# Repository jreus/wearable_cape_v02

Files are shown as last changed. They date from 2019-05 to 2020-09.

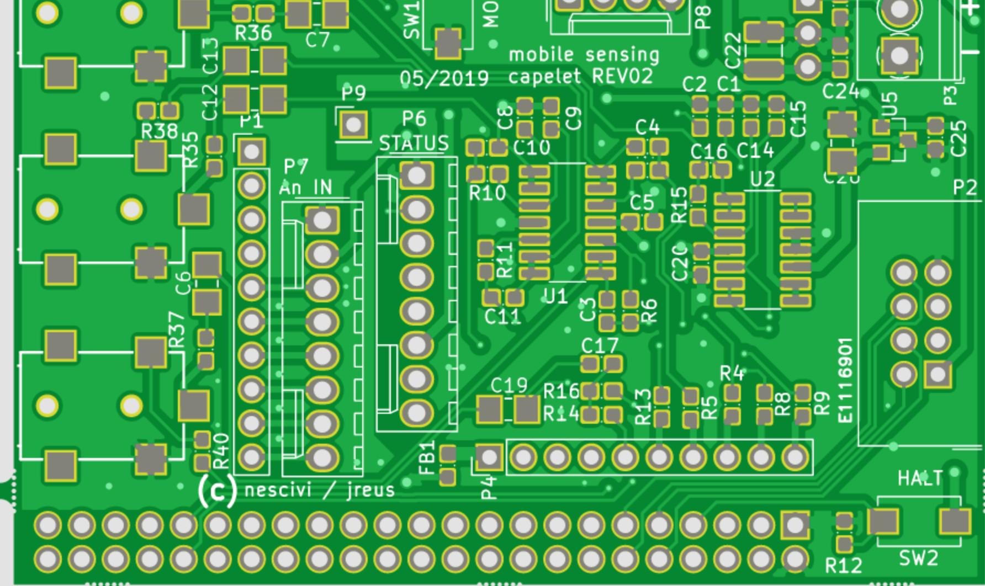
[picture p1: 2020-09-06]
images/REV2.1_wiring_mistake/Screen Shot 2019-05-27 at 19.32.11.png

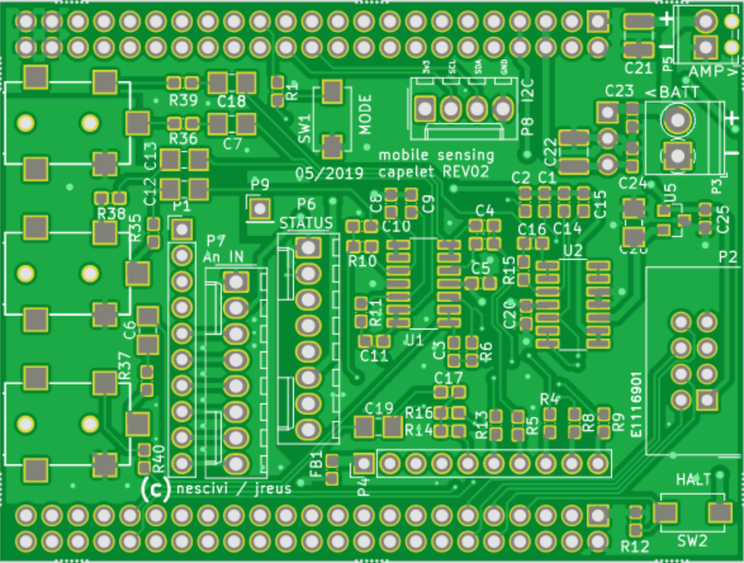
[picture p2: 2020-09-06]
images/REV2.1_wiring_mistake/CUTS-TOP.png

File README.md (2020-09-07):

# wearable_cape_v02

Second version of a wearable sensing/actuating cape for the Augmented Attention Lab (June 2019)

## Changes from v01
- fixed wiring errors from filter circuits to minijack outputs
- removed unused resistors from filter design (two in final stage, one in input stage)
- swapped out resistor-based voltage divider for a dedicated 1.8V reference (MAX6100)
- breakout header for analog inputs
- widen power rail traces from battery to 11.1V source to amplifiers

# 23 MAY 2019 ~ WARNING! First Boards Ordered from Eurocircuits have wiring mistakes!
There was a serious wiring error in these boards, where the 10-pin row of headers that
connect downward into the Bela's analog inputs row and analog outputs row are reversed!
These headers do not correctly match up to the pins on the Bela and thus need to be
sliced and re-routed on the capelet board.

The pin ordering is flipped. So for example, on the Bela, the ground header for analog inputs is
on the bottom. But on the capelet it's at the top.

Likewise, on the Bela the analog outputs ground is on the right, on the capelet it's on the
left.

Possible Solutions (other than making new boards!):

1. Make a pin header/wire adapter that reverses the connections
2. Cut n rewire the capelet

See images/REV2.1_wiring_mistake for more info on the wiring issue...

## More errors
The mode select and halt switches are misnamed on the board, and potentially miswired to the breakout board header.

The actual wiring of the status header on the v2 board is...

1 ~ GND
2 ~ STATUS_LED
3 ~ D11
4 ~ SW_HALT
5 ~ D8
6 ~ MODE_SEL1 / 3v3
7 ~ D9
8 ~ MODE_SEL2

## ToDos (future work)
- Add bypass capacitors to the active filters
- silkscreen labels for switch functionality and outputs
- breakout capability of mode switch, reset switch, & status LEDs
  - user leds, see: http://beaglebone.cameon.net/home/using-the-user-leds
- add additional 2-channel output for full access to all output channels

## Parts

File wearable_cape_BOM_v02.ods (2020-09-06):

Reference | Quantity | Value | Footprint | Supplier | Part No | Cost | Total Cost | in stock | needed | part page
C2 C1 C9 C8 C14 C15 | 6 | 220pF | C0603 | Farnell | 430948 | 0.0645 |  |  |  | https://nl.farnell.com/yageo/cc0603jrnpo9bn221/cap-220pf-50v-5-c0g-np0-0603/dp/430948
C21 C22 | 2 | 10uF | jcr-device:C_1210
C4 C3 C11 C10 C16 C17 | 6 | 440pF (part is 470pF) | C0603 | Farnell | 2496906 | 0.06 |  |  |  | https://nl.farnell.com/walsin/0603n471j500ct/cap-470pf-50v-5-c0g-np0-0603/dp/2496906
C5 C20 C23 C24 C25 | 5 | 100nF | jcr-device:C_0603_SMD_HandSolder | Farnell | 2320793 | 0.0421 |  |  |  | https://nl.farnell.com/multicomp/mc0603b104j250ct/cap-0-1-f-25v-5-x7r-0603/dp/2320793
C7 C6 C13 C12 C18 C19 C26 | 7 | 1uF | jcr-device:C_1206
FB1 | 1 | FILTER | 0603 Ferrite Bead | Farnell | 1781090 | 0.046 |  |  |  | https://nl.farnell.com/murata/blm18kg221sn1d/ferrite-bead-0603-220r-2-2a/dp/1781090
J1 J2 J3 | 3 | Minijack Socket | Lumberg:Lumberg_1503_03 | Farnell | 1216980 | 2.87 |  |  |  | https://nl.farnell.com/lumberg/1503-03/connector-receptacle-3-5mm-phono/dp/1216980
P1 | 1 | BELA_AINS | jcr-conn:PinHeader_1x10_P2.54mm_Vertical
P2 | 1 | SERIAL_BREAKOUT | jcr-conn:IDC-Header_2x04_P2.54mm_Vertical
P3 | 1 | CONN_01X02_BATTERY | jcr-conn:TerminalBlock_Phoenix_PT_H_1x02_P3.50mm
P4 | 1 | BELA_AOUTS | jcr-conn:PinHeader_1x10_P2.54mm_Vertical
P5 | 1 | PWR_OUT_AMPS | jcr-conn:TerminalBlock_Phoenix_MPT_1x02_P2.54mm
P6 P7 | 2 | 8-pin Molex | jcr-conn:Molex_KK-254_1x08_P2.54mm_Vertical
P8 | 1 | 4-pin Molex | jcr-conn:Molex_KK-254_1x04_P2.54mm_Vertical
P9 | 1 | CONN_1 | jcr-conn:PinHeader_1x01_P2.54mm_Vertical
R1 | 1 | 100 | R0603 | Farnell | 2447227 | 0.006 |  |  |  | https://nl.farnell.com/multicomp/mcwr06x1000ftl/res-100r-1-0-1w-0603-thick-film/dp/2447227
R12 | 1 | 10k | R0603 | Farnell | 2447230 | 0.006 |  |  |  | https://nl.farnell.com/multicomp/mcwr06x1002ftl/res-10k-1-0-1w-0603-thick-film/dp/2447230
R37 R36 R35 R40 R39 R38 | 6 | 12k | R0603 | Farnell | 2447243 | 0.0059 |  |  |  | https://nl.farnell.com/multicomp/mcwr06x1202ftl/res-12k-1-0-1w-thick-film/dp/2447243
R7 R5 R6 R4 R11 R9 R10 R8 R15 R13 R16 R14 | 12 | 28.7k | R0603 | Farnell | 2447318 | 0.006 |  |  |  | https://nl.farnell.com/multicomp/mcwr06x2872ftl/res-28k7-1-0-1w-thick-film/dp/2447318
SW1 | 1 | SW_HALT | jcr-mechanical:SW_SPST_EVQPE1
SW2 | 1 | SW_MODE_SEL | jcr-mechanical:SW_SPST_EVQPE1
U1 U2 | 2 | MCP6004 | jcr-ic:SOIC-14_3.9x8.7mm_P1.27mm
U3 | 1 | BEAGLEBONEBLACK | BBB:beagleboneblack_nomount
U4 | 1 | OKI_78SR-5 | OKI-78SR_Horizontal | Documentation/Datasheets/oki-78sr-1.pdf
U5 | 1 | MAX6100 | SOT-23
External components
voltage regulator | OKI-78SR-5/1.5-W36-C | 1 |  | Farnell | 2102101 | € 7.3500 |  |  |  | € 7.3500 | 4 | 3 | 2102101 | -1
Amplifier board | Stereo 20W amp, MAX9744 | 3 |  | Kiwi Electronics | ADA-1752 | € 19.2000 | € 192.00 | 10 | 10 | € 57.6000 | 10 | 9
DC barrel cable |  | 1 |  | Bax electronics | http://www.bax-shop.nl/gitaareffect-voeding-adapter/mooer-pdc-5a-daisy-chain-dc-power-cable | € 5.3000 |  |  |  | € 5.3000 | 3 | 3
audio cable minijack – minijack |  | 3 |  | Bax electronics | http://www.bax-shop.nl/index.php?Itemid=2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 | € 1.5300 |  |  |  | € 4.5900 | 9 | 9
Distance screws for amplifier boards |  | 8 |  | Farnell | 2345351 | € 0.4640 | € 0.46 | 1 | 1 | € 1.3920 | 1 | 24 | 2345351 | 23
8-pin molex wire-2-board connectors KK 254 |  | 8 |  | Farnell | 2311419 | € 0.7820 | € 0.78 | 1 | 10 | € 6.2560 | 1 | 24 | 2311419 | 23
8-pin HDC connectors (male) |  | 8 |  | Farnell | 2494522 | € 0.0810 | € 0.08 | 1 | 10 | € 0.6480 | 10 | 24 | 2494522 | 14
IDC cable to receiver |  | 1 |  | Farnell | 2217620 | € 2.3700 |  |  |  | € 2.3700 | 1 | 3 | 2217620 | 2
BATTERY
cables HXT to wire |  | 1 |  | Hobby King | http://www.hobbyking.com/hobbyking/store/__24423__HXT4mm_w_12AWG_Silicon_Wire_10cm_ESC_side_5pcs_Bag_.html
5000 mAh battery |  | 1 |  | Hobby King | http://www.hobbyking.com/hobbyking/store/uh_viewitem.asp?idproduct=35834
HXT to bananaplug adapter |  | 1 |  | Hobby King | https://www.hobbyking.com/hobbyking/store/uh_viewItem.asp?idProduct=31487
low battery warning circuit |  | 1 |  | Hobby King | http://www.hobbyking.com/hobbyking/store/__41734__HobbyKing_8482_Lipoly_Low_Voltage_Alarm_2s_3s_EU_Warehouse_.html
battery charger |  | 1 |  | Hobby King | https://www.hobbyking.com/hobbyking/store/uh_viewItem.asp?idProduct=95979

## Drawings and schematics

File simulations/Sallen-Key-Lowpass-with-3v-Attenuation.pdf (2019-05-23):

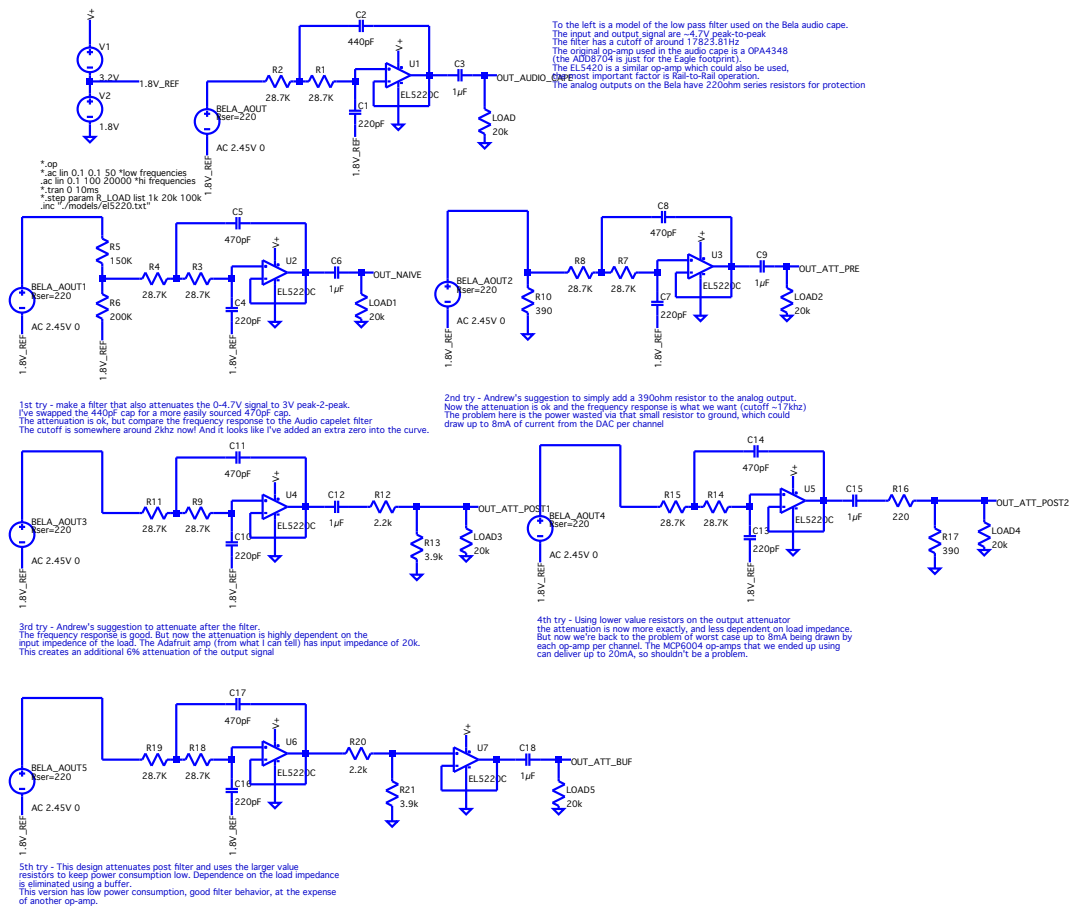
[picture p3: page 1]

To the left is a model of the low pass filter used on the Bela audio cape.
The input and output signal are ~4.7V peak-to-peak
The filter has a cutoff of around 17823.81Hz
The original op-amp used in the audio cape is a OPA4348
(the ADD8704 is just for the Eagle footprint).
The EL5420 is a similar op-amp which could also be used,
the most important factor is Rail-to-Rail operation.
The analog outputs on the Bela have 220ohm series resistors for protection

*.ac lin 0.1 0.1 50 *low frequencies
.ac lin 0.1 100 20000 *hi frequencies
*.tran 0 10ms
*.step param R_LOAD list 1k 20k 100k
.inc "./models/el5220.txt"

1st try - make a filter that also attenuates the 0-4.7V signal to 3V peak-2-peak.
I've swapped the 440pF cap for a more easily sourced 470pF cap.
The attenuation is ok, but compare the frequency response to the Audio capelet filter
The cutoff is somewhere around 2khz now! And it looks like I've added an extra zero into the curve.

2nd try - Andrew's suggestion to simply add a 390ohm resistor to the analog output.
Now the attenuation is ok and the frequency response is what we want (cutoff ~17khz)
The problem here is the power wasted via that small resistor to ground, which could
draw up to 8mA of current from the DAC per channel

3rd try - Andrew's suggestion to attenuate after the filter.
The frequency response is good. But now the attenuation is highly dependent on the
input impedence of the load. The Adafruit amp (from what I can tell) has input impedance of 20k.
This creates an additional 6% attenuation of the output signal

4th try - Using lower value resistors on the output attenuator
the attenuation is now more exactly, and less dependent on load impedance.
But now we're back to the problem of worst case up to 8mA being drawn by
each op-amp per channel. The MCP6004 op-amps that we ended up using
can deliver up to 20mA, so shouldn't be a problem.

5th try - This design attenuates post filter and uses the larger value
resistors to keep power consumption low. Dependence on the load impedance
is eliminated using a buffer.
This version has low power consumption, good filter behavior, at the expense
of another op-amp.

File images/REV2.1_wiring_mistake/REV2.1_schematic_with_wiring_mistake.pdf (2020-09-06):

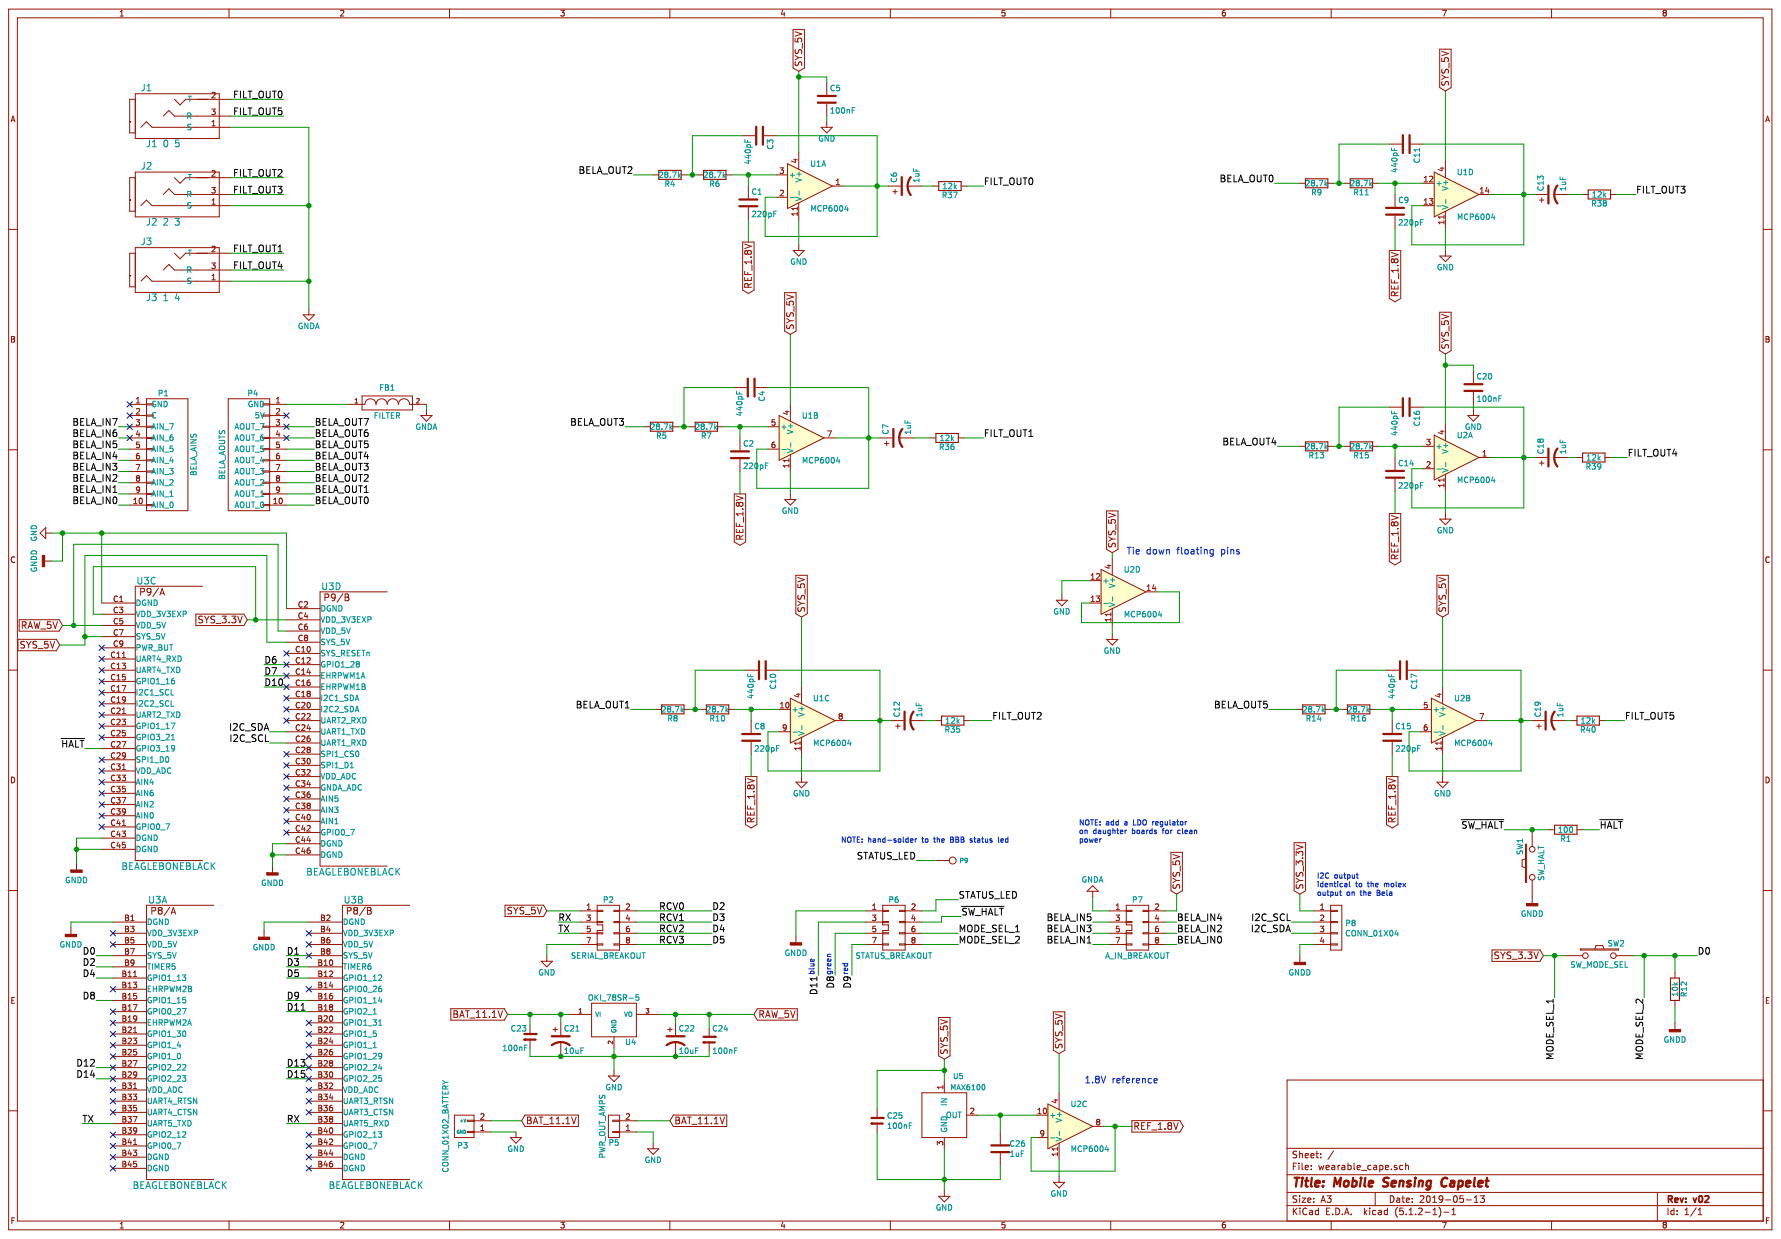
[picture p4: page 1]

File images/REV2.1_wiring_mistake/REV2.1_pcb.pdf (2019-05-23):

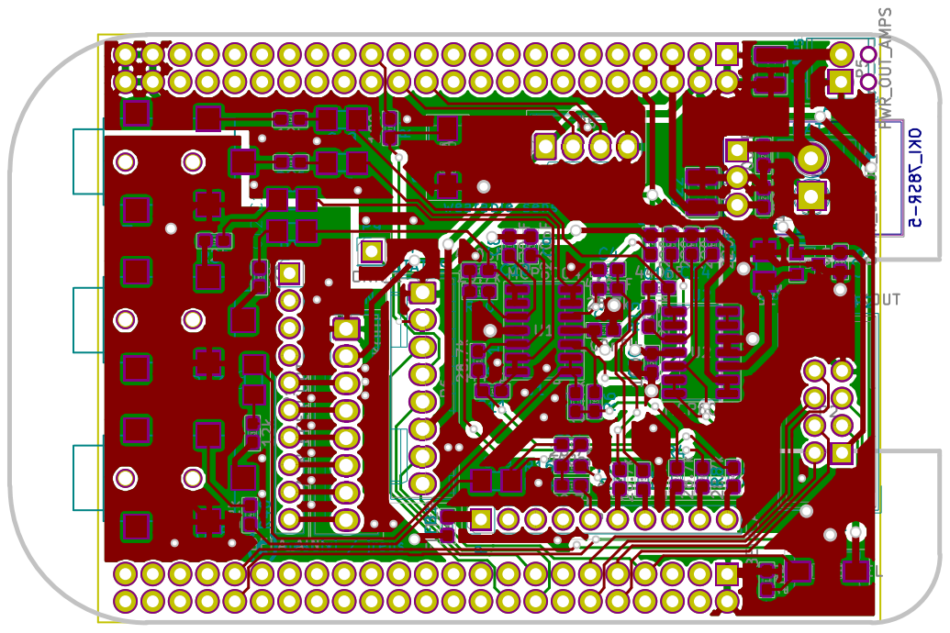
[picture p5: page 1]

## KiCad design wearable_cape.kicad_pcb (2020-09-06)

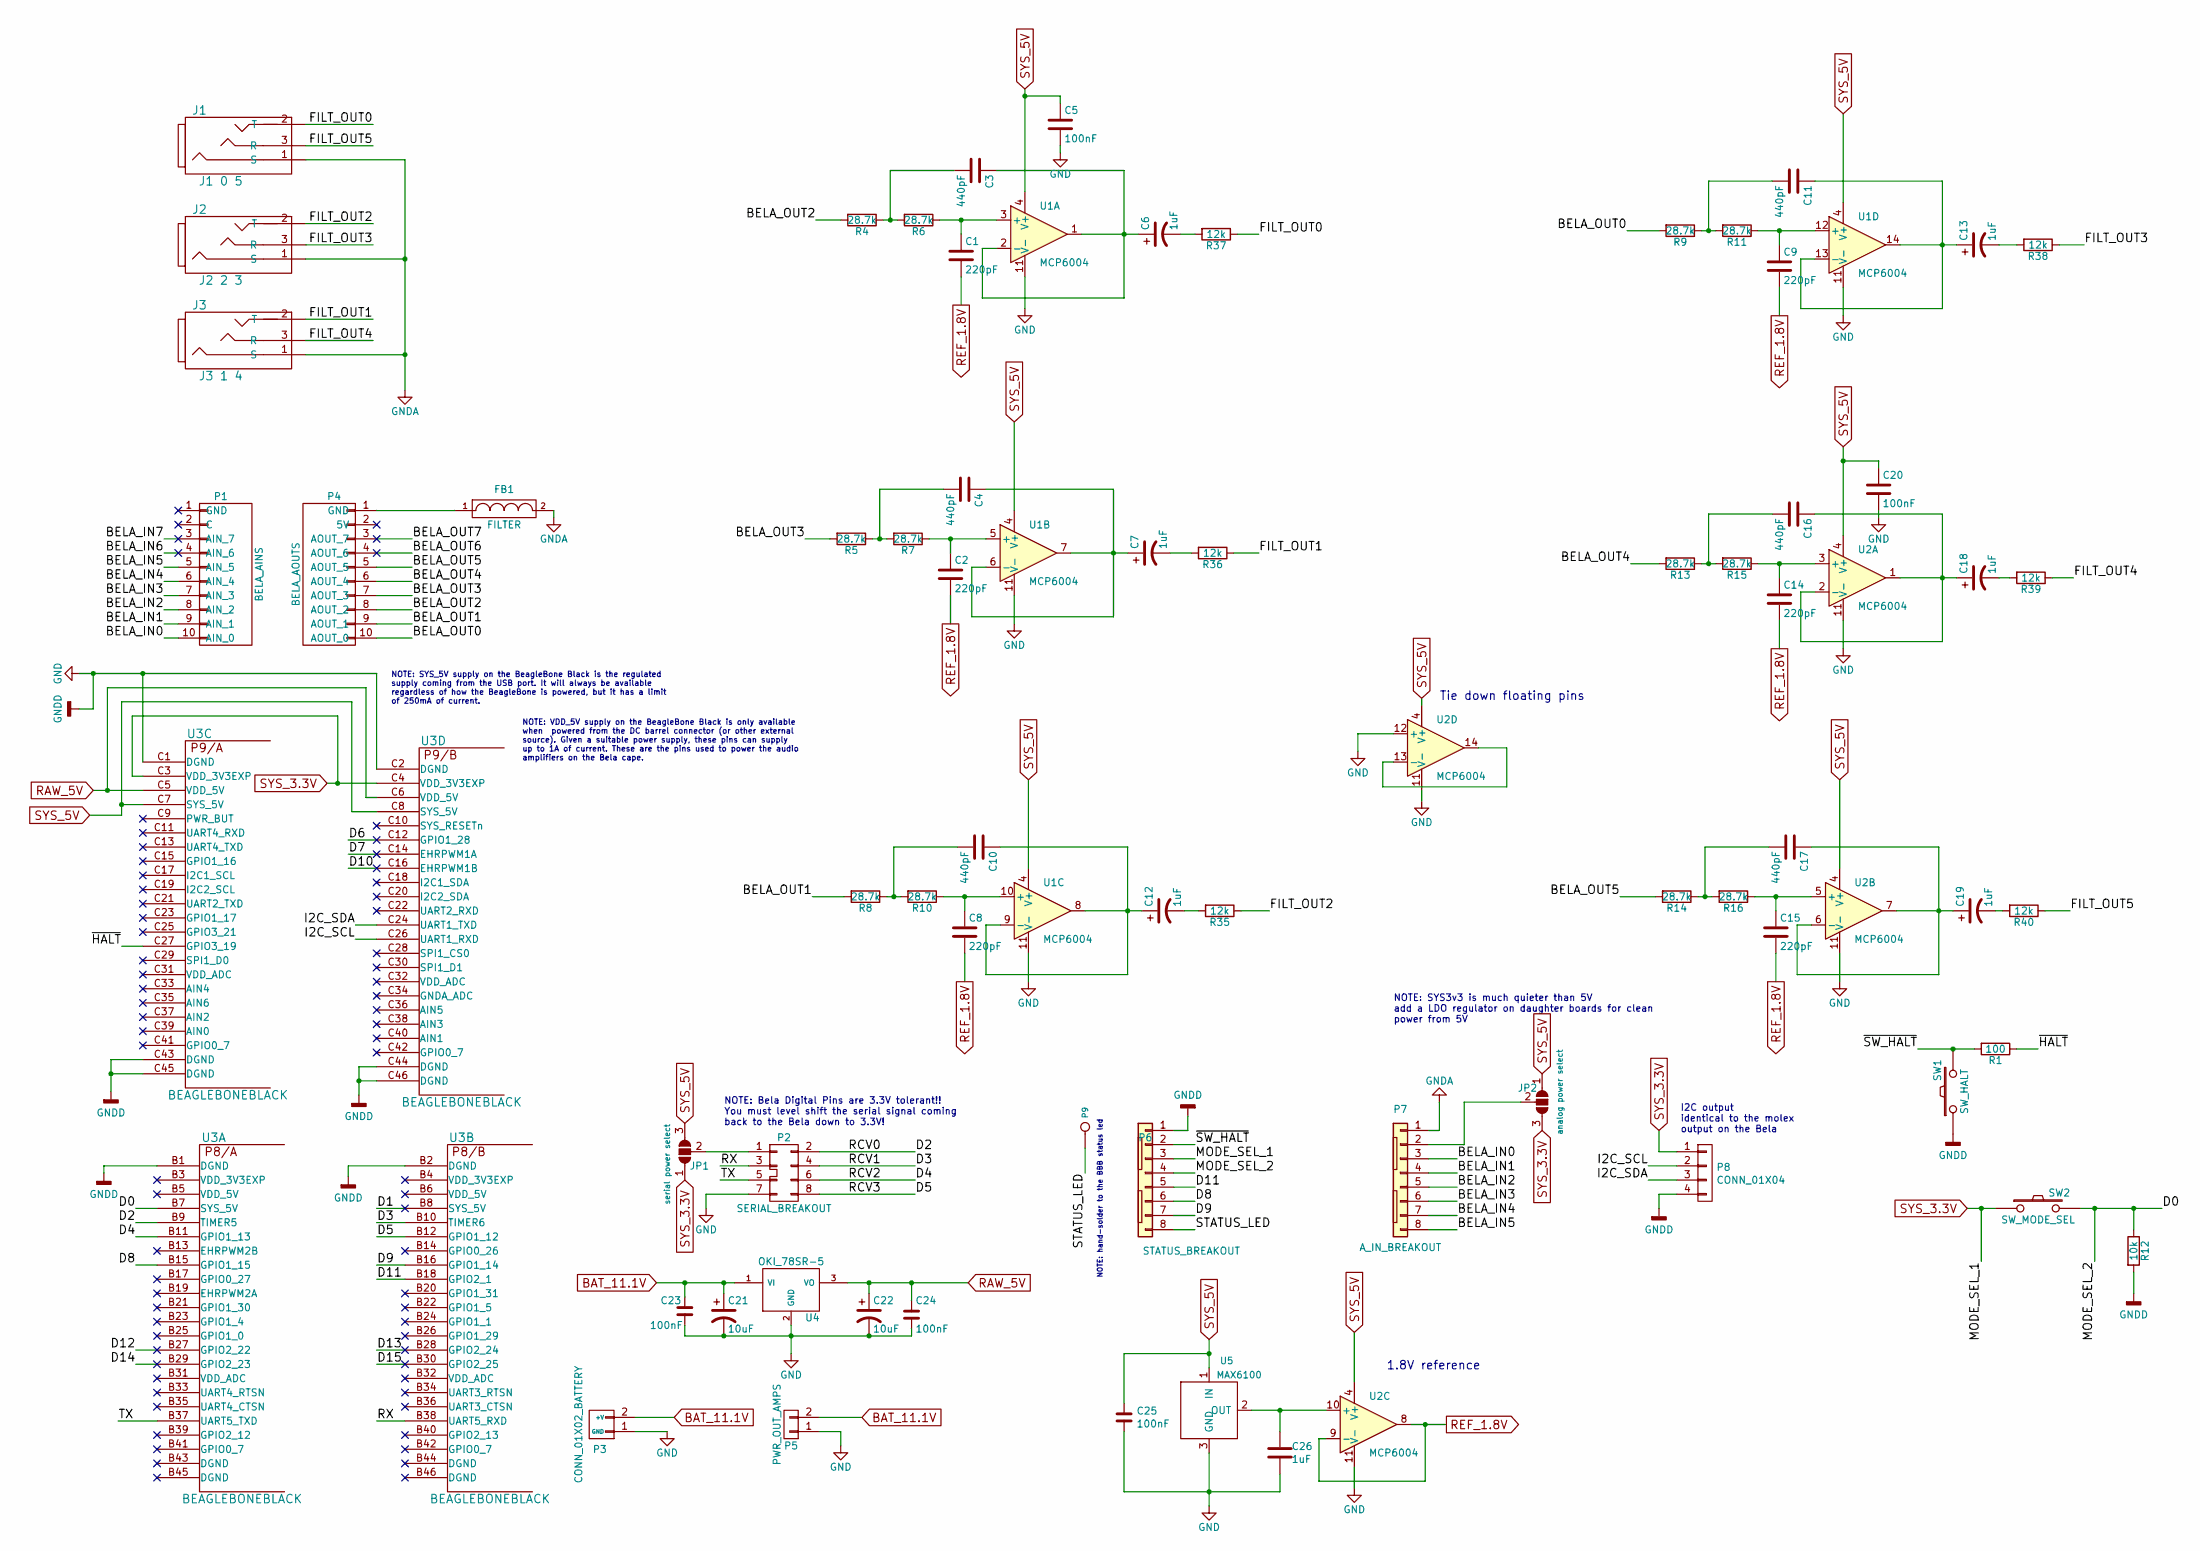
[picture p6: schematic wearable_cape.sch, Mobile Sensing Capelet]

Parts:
C1, C2, C8, C9, C14, C15: 220pF; C_0603_SMD_HandSolder
C3, C4, C10, C11, C16, C17: 440pF; C_0603_SMD_HandSolder
C5, C20, C23, C24, C25: 100nF; C_0603_SMD_HandSolder
C6, C7, C12, C13, C18, C19, C26: 1uF; C_1206
C21, C22: 10uF; C_1210
FB1: FILTER; L_0603_SMD_Handsolder
J1: J1 0 5; Lumberg_1503_03
J2: J2 2 3; Lumberg_1503_03
J3: J3 1 4; Lumberg_1503_03
JP1: serial power select; SolderJumper-3_P1.3mm_Open_Pad1.0x1.5mm
JP2: analog power select; SolderJumper-3_P1.3mm_Open_Pad1.0x1.5mm
P1: BELA_AINS; PinHeader_1x10_P2.54mm_Vertical
P2: SERIAL_BREAKOUT; IDC-Header_2x04_P2.54mm_Vertical
P3: CONN_01X02_BATTERY; TerminalBlock_Phoenix_PT_H_1x02_P3.50mm
P4: BELA_AOUTS; PinHeader_1x10_P2.54mm_Vertical
P5: PWR_OUT_AMPS; TerminalBlock_Phoenix_MPT_1x02_P2.54mm
P6: STATUS_BREAKOUT; Molex_KK-254_1x08_P2.54mm_Vertical
P7: A_IN_BREAKOUT; Molex_KK-254_1x08_P2.54mm_Vertical
P8: CONN_01X04; Molex_KK-254_1x04_P2.54mm_Vertical
P9: CONN_1; PinHeader_1x01_P2.54mm_Vertical
R1: 100; R_0603_SMD_Handsolder
R4, R5, R6, R7, R8, R9, R10, R11, R13, R14, R15, R16: 28.7k; R_0603_SMD_Handsolder
R12: 10k; R_0603_SMD_Handsolder
R35, R36, R37, R38, R39, R40: 12k; R_0603_SMD_Handsolder
SW1: SW_HALT; SW_SPST_EVQPE1
SW2: SW_MODE_SEL; SW_SPST_EVQPE1
U1, U2: MCP6004; SOIC-14_3.9x8.7mm_P1.27mm
U3: BEAGLEBONEBLACK; beagleboneblack_nomount
U4: OKI_78SR-5; Converter_DCDC_muRata_OKI-78SR_Horizontal
U5: MAX6100; SOT-23

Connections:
/BELA_IN0: P1.10 (AIN_0), P7.3
/BELA_IN1: P1.9 (AIN_1), P7.4
/BELA_IN2: P1.8 (AIN_2), P7.5
/BELA_IN3: P1.7 (AIN_3), P7.6
/BELA_IN4: P1.6 (AIN_4), P7.7
/BELA_IN5: P1.5 (AIN_5), P7.8
/BELA_IN6: P1.4 (AIN_6)
/BELA_IN7: P1.3 (AIN_7)
/BELA_OUT0: P4.10 (AOUT_0), R9.2
/BELA_OUT1: P4.9 (AOUT_1), R8.2
/BELA_OUT2: P4.8 (AOUT_2), R4.2
/BELA_OUT3: P4.7 (AOUT_3), R5.2
/BELA_OUT4: P4.6 (AOUT_4), R13.2
/BELA_OUT5: P4.5 (AOUT_5), R14.2
/BELA_OUT6: P4.4 (AOUT_6)
/BELA_OUT7: P4.3 (AOUT_7)
/D0: P6.4, R12.1, SW2.2, U3.B7 (SYS_5V)
/D1: U3.B8 (SYS_5V)
/D2: P2.2, U3.B9 (TIMER5)
/D3: P2.4, U3.B10 (TIMER6)
/D4: P2.6, U3.B11 (GPIO1_13)
/D5: P2.8, U3.B12 (GPIO1_12)
/D6: U3.C12 (GPIO1_28)
/D7: U3.C14 (EHRPWM1A)
/D8: P6.6, U3.B15 (GPIO1_15)
/D9: P6.7, U3.B16 (GPIO1_14)
/D10: U3.C16 (EHRPWM1B)
/D11: P6.5, U3.B18 (GPIO2_1)
/D12: U3.B27 (GPIO2_22)
/D13: U3.B28 (GPIO2_24)
/D14: U3.B29 (GPIO2_23)
/D15: U3.B30 (GPIO2_25)
/FILT_OUT0: J1.2 (T), R37.1
/FILT_OUT1: J3.2 (T), R36.1
/FILT_OUT2: J2.2 (T), R35.1
/FILT_OUT3: J2.3 (R), R38.1
/FILT_OUT4: J3.3 (R), R39.1
/FILT_OUT5: J1.3 (R), R40.1
/I2C_SCL: P8.2, U3.C26 (UART1_RXD)
/I2C_SDA: P8.3, U3.C24 (UART1_TXD)
/RX: P2.3, U3.B38 (UART5_RXD)
/STATUS_LED: P6.8, P9.1
/TX: P2.5, U3.B37 (UART5_TXD)
/~HALT: R1.1, U3.C27 (GPIO3_19)
/~SW_HALT: P6.2, R1.2, SW1.2
BAT_11.1V: C21.1, C23.1, P3.2 (+V), P5.2, U4.1 (VI)
GND: C5.2, C20.2, C21.2, C22.2, C23.2, C24.2, C25.2, C26.2, P2.7, P3.1 (GND), P5.1, P6.1, P8.4, R12.2, SW1.1, U1.11 (V-), U2.11 (V-), U2.12 (+), U3.B1 (DGND), U3.B2 (DGND), U3.C1 (DGND), U3.C2 (DGND), U3.C43 (DGND), U3.C44 (DGND), U3.C45 (DGND), U3.C46 (DGND), U4.2 (GND), U5.3 (GND)
GNDA: FB1.2, J1.1 (S), J2.1 (S), J3.1 (S), P7.1
unnamed: C1.1, R6.1, U1.3 (+)
unnamed: C2.1, R7.1, U1.5 (+)
unnamed: C3.1, C6.1, U1.1, U1.2 (-)
unnamed: C3.2, R4.1, R6.2
unnamed: C4.1, C7.1, U1.6 (-), U1.7
unnamed: C4.2, R5.1, R7.2
unnamed: C6.2, R37.2
unnamed: C7.2, R36.2
unnamed: C8.1, R10.1, U1.10 (+)
unnamed: C9.1, R11.1, U1.12 (+)
unnamed: C10.1, C12.1, U1.8, U1.9 (-)
unnamed: C10.2, R8.1, R10.2
unnamed: C11.1, C13.1, U1.13 (-), U1.14
unnamed: C11.2, R9.1, R11.2
unnamed: C12.2, R35.2
unnamed: C13.2, R38.2
unnamed: C14.1, R15.1, U2.3 (+)
unnamed: C15.1, R16.1, U2.5 (+)
unnamed: C16.1, C18.1, U2.1, U2.2 (-)
unnamed: C16.2, R13.1, R15.2
unnamed: C17.1, C19.1, U2.6 (-), U2.7
unnamed: C17.2, R14.1, R16.2
unnamed: C18.2, R39.2
unnamed: C19.2, R40.2
unnamed: C26.1, U2.10 (+), U5.2 (OUT)
unnamed: FB1.1, P4.1 (GND)
unnamed: JP1.2 (C), P2.1
unnamed: JP2.2 (C), P7.2
unnamed: U2.13 (-), U2.14
RAW_5V: C22.1, C24.1, U3.C5 (VDD_5V), U3.C6 (VDD_5V), U4.3 (VO)
REF_1.8V: C1.2, C2.2, C8.2, C9.2, C14.2, C15.2, U2.8, U2.9 (-)
SYS_3.3V: JP1.1 (A), JP2.3 (B), P6.3, P8.1, SW2.1, U3.C3 (VDD_3V3EXP), U3.C4 (VDD_3V3EXP)
SYS_5V: C5.1, C20.1, C25.1, JP1.3 (B), JP2.1 (A), U1.4 (V+), U2.4 (V+), U3.C7 (SYS_5V), U3.C8 (SYS_5V), U5.1 (IN)

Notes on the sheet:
1.8V reference
I2C output identical to the molex output on the Bela
NOTE: SYS3v3 is much quieter than 5V add a LDO regulator on daughter boards for clean power from 5V
NOTE: hand-solder to the BBB status led
Tie down floating pins
NOTE: Bela Digital Pins are 3.3V tolerant!! You must level shift the serial signal coming back to the Bela down to 3.3V!
NOTE: SYS_5V supply on the BeagleBone Black is the regulated supply coming from the USB port. It will always be available regardless of how the BeagleBone is powered, but it has a limit of 250mA of current.
NOTE: VDD_5V supply on the BeagleBone Black is only available when powered from the DC barrel connector (or other external source). Given a suitable power supply, these pins can supply up to 1A of current. These are the pins used to power the audio amplifiers on the Bela cape.

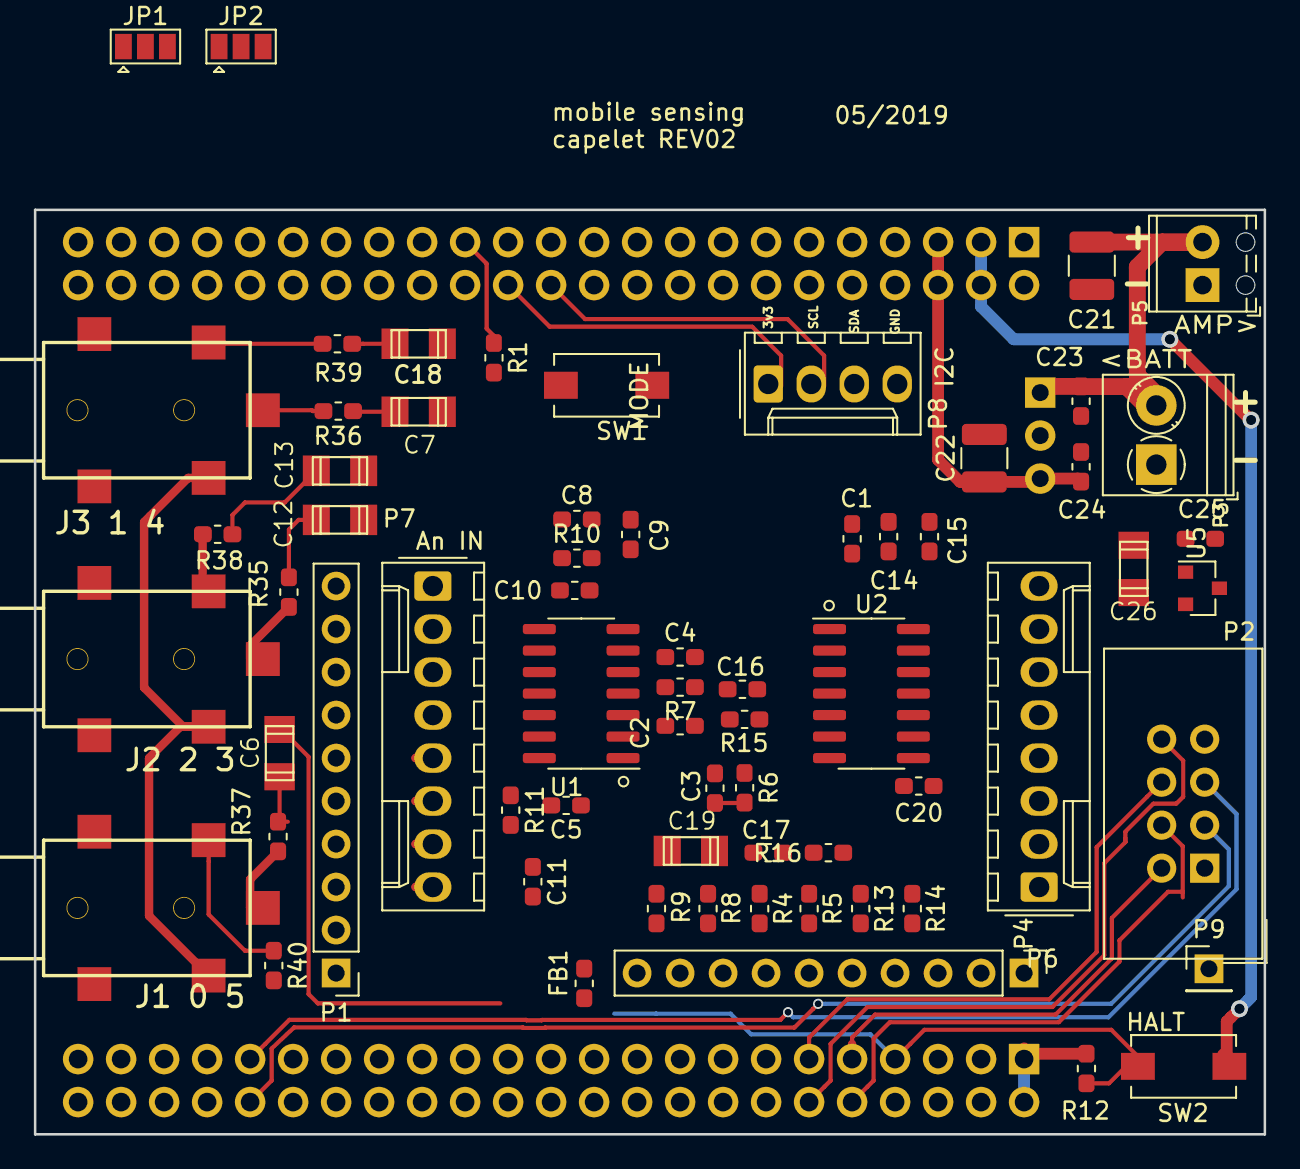
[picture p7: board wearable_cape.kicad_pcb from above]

Board: 2 copper layers, 72.6 x 54.6 mm, 68 parts (1 on the bottom side), 69 nets.

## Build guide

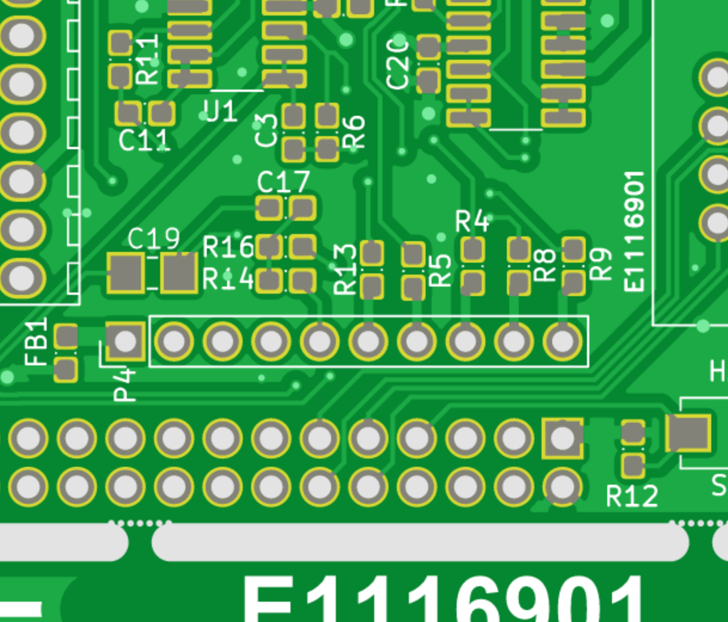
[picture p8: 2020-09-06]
images/REV2.1_wiring_mistake/Screen Shot 2019-05-27 at 11.47.39.png

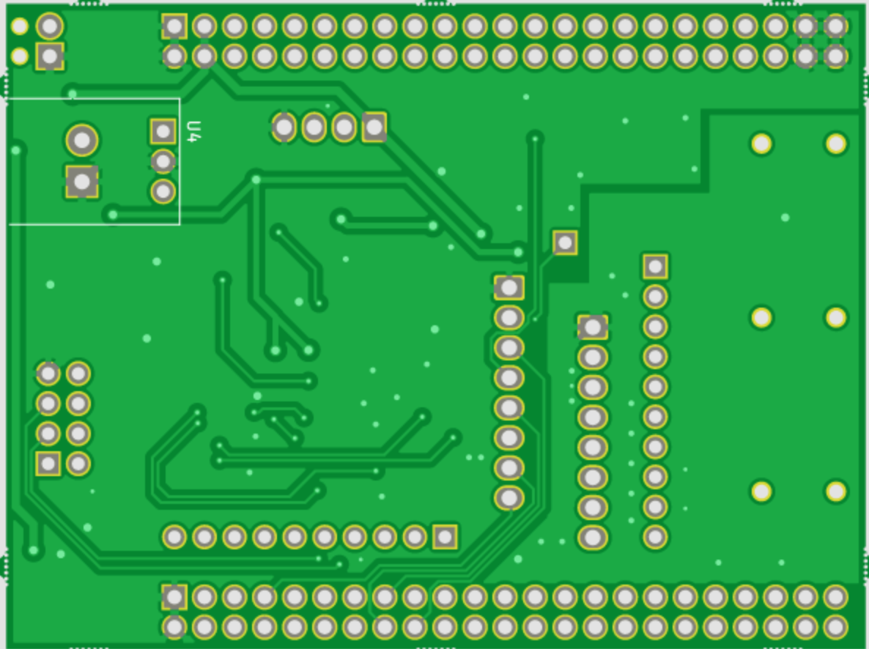
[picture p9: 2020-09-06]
images/REV2.1_wiring_mistake/CUTS-BOTTOM.png

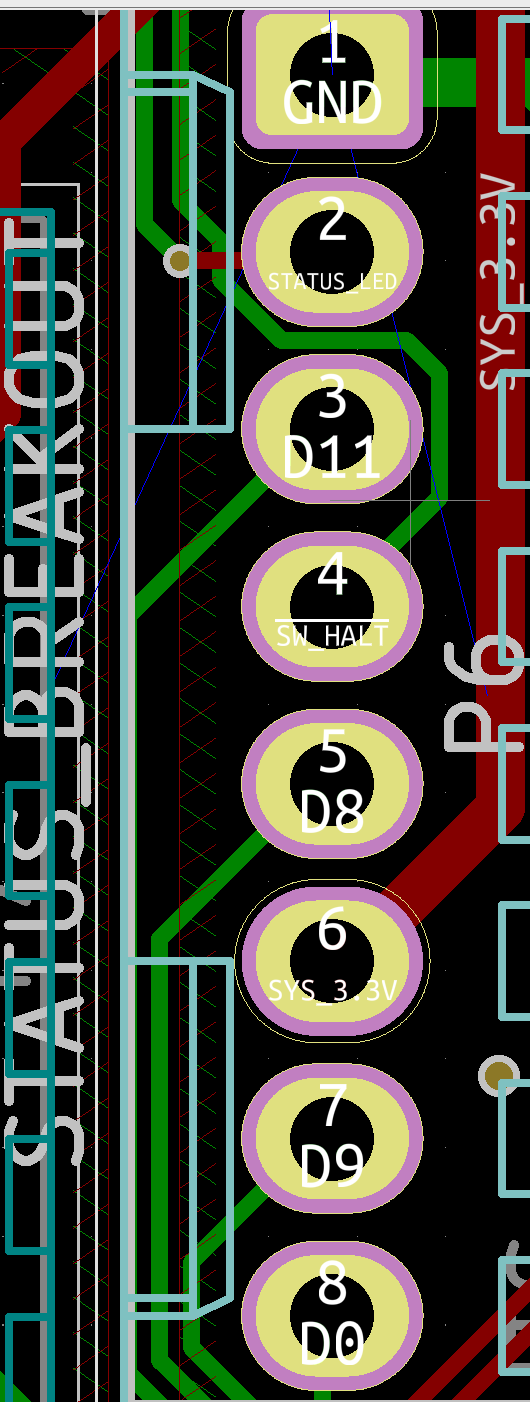
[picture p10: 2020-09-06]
images/REV2.1_wiring_mistake/Screen Shot 2019-05-23 at 22.55.02.png

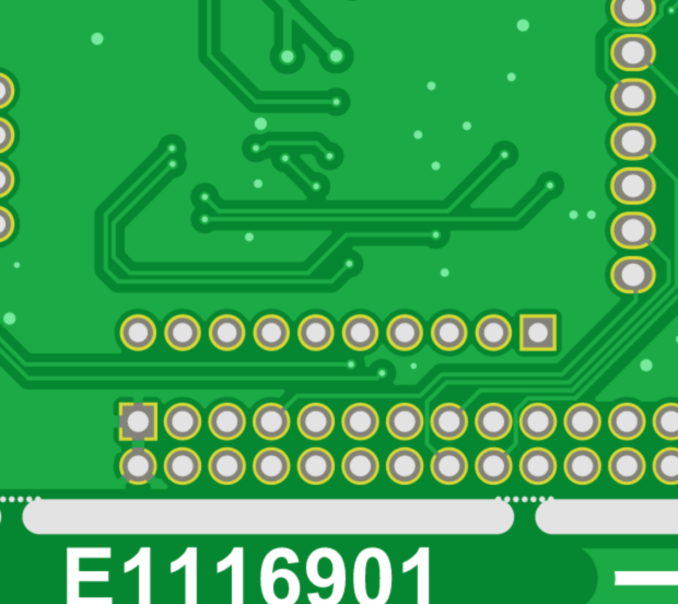
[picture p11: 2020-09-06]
images/REV2.1_wiring_mistake/Screen Shot 2019-05-27 at 11.47.55.png

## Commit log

2020-09-06 updates - wiring mistake!
    [wearable_cape (1).sch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]
2020-09-07 updates to v2 schematics with notations on wiring errors
    [wearable_cape.sch]
